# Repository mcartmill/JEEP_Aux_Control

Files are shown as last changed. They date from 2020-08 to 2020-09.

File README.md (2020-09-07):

# JEEP_Aux_Control
Control for aux accessories like additional lighting using a touchscreen control.

Goal

I am creating an open source solution to controlling additional electronic components such as lights.  

Conditions:
1.    Must be stand alone, not connecting to existing systems of the Jeep.
2.    Easy to customize
3.    Low Cost
4.    All documents available for anyone to use (code, PCB files, GRB files)
5.    Allow others to add to the documentation for functionality and defects

____________________________________________________________________________________
MCU Code

Code uses Ardiuno code for ease of use.
Jeep_AUX_Control.ino.ino

____________________________________________________________________________________
Touchscreen Code

Since using Nextion screen, UI code uses Nextion Editor Software - Free and easy to use.

____________________________________________________________________________________

Power Circuit code

Code for power circuit using ATTiny85 - attiny85powerlogicv0.1.ino

Power Circuit Theory of Operations

12V constant and 12V switched (identified as ignition in this document) comes into the circuit.  These are regulated down to 5V constant, 5V ignition, and 5V Ignition w/Delay off.

ATTiny85 is used to control 5V Ignition w/Delay by monitoring 5V Ignition into digital pin 0.  When digital pin 0 goes low, the chip sees this as ignition is off and then runs a delay and then sets digital pin 1 to low, which is the output that controls a transistor as a switch for the 5V Ignition w/Delay.

ATTiny85 Pinout
Pin4 = GND
Pin5= Digital Pin 0 = Input from 5V ignition
Pin6= Digital Pin 1 = Output to control transistor for delayed 5V ignition
Pin8= VCC (5V Constant)

Theory of Operations for ATTiny85 Code

Digital Pin0 = input
Digital Pin1 = output = init high

While pin0 is low then pin1==LOW

____________________________________________________________________________________
PCB

PCB files made in Eagle CAD.  Include ready to print files for https://jlcpcb.com/

Power Circuit PCB - power reg 5v_2019-04-10.zip

Control PCB JEEP_Aux_Control_PCB.brd and JEEP_Aux_Control_PCB.sch
JEEP_Aux_Control_PCB_2020-09-06.zip is the complete cam output to send to PCB house for production

____________________________________________________________________________________
BOM

BOM along with sources for parts
 
Control Board BOM
https://www.mouser.com/ProjectManager/ProjectDetail.aspx?AccessID=32fda13301

Power Board BOM
https://www.mouser.com/ProjectManager/ProjectDetail.aspx?AccessID=7aa37e28ff
 
Touchscreen
https://www.amazon.com/Nextion-NX4024T032-Display-Arduino-Raspberry/dp/B07QYRB38T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
 
Relays
https://www.amazon.com/ONLINE-LED-STORE-Pack-Interlocking/dp/B01KVZ2MU4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

____________________________________________________________________________________
3D models

____________________________________________________________________________________
Github file location:

https://github.com/mcartmill/JEEP_Aux_Control

____________________________________________________________________________________
Youtube videos

https://youtu.be/mUTJI6I0mCo

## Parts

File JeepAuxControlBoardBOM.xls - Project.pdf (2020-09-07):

JEEP AUX CONTROL
Mouser # | Mfr. # | Manufacturer | Customer # Description | RoHS | Lifecycle Order Qty. Price (USD) Ext.: (USD)
512-SB1100 | SB1100 | ON Semiconductor | Schottky Diodes & Rectifiers Schottky Diode | RoHS Compliant | 6 $0.36 | $2.16
559-FOXSD160-20-LF | FOXSDLF/160-20 | Fox | Crystals 16MHz 20pF | RoHS Compliant | 1 $0.27 | $0.27
581-06035A220J | 06035A220JAT2A | AVX | Multilayer Ceramic Capacitors MLCC - SMD/SMT 50V 22pF C0G 0603 5%RoHS Compliant | 2 $0.10 | $0.20
556-ATMEGA328P-PU | ATMEGA328P-PU | Microchip | 8-bit Microcontrollers - MCU 32KB In-system Flash 20MHz 1.8V-5.5V RoHS Compliant | 1 $2.08 | $2.08
571-1-2199298-9 | 1-2199298-9 | TE Connectivity | IC & Component Sockets 28P DIP SKT 300 CL LADDER | RoHS Compliant | 1 $0.46 | $0.46
594-MCT0603PD1001DP5 | MCT0603PD1001DP500 Vishay | Thin Film Resistors - SMD .250W 1Kohms .5% 0603 25ppm Hi Power | RoHS Compliant By Exemption | 6 $0.57 | $3.42
78-4N32 | 4N32 | Vishay | Transistor Output Optocouplers Photodarlington Out | RoHS Compliant | 6 $0.65 | $3.90

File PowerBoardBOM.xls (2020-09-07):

POWERBOARD
Mouser # | Mfr. # | Manufacturer | Customer # | Description | RoHS | Lifecycle | Order Qty. | Price (USD) | Ext.: (USD)
926-LM7805CT/NOPB | LM7805CT/NOPB | Texas Instruments |  | Linear Voltage Regulators 5 Volt Reg | RoHS Compliant |  | 2 | $1.54 | $3.08
81-GRM188R6YA106MA3D | GRM188R6YA106MA73D | Murata |  | Multilayer Ceramic Capacitors MLCC - SMD/SMT 0603 10uF 35volts *Derate Voltage/Temp | RoHS Compliant |  | 4 | $0.50 | $2.00
653-G5LE-1-ASIDC5 | G5LE-1-ASI DC5 | Omron |  | General Purpose Relays Power PCB Relay | RoHS Compliant |  | 1 | $1.45 | $1.45
594-MFU0805-FF-1.0 | MFU0805FF01000P500 | Vishay |  | Surface Mount Fuses 50V 1.0A Fast Act | RoHS Compliant |  | 2 | $0.41 | $0.82
556-ATTINY85-20SU | ATTINY85-20SU | Microchip |  | 8-bit Microcontrollers - MCU AVR 8K FLSH 512B EE 512B SRAM ADC 5V | RoHS Compliant |  | 1 | $1.13 | $1.13
512-2N3904BU | 2N3904BU | ON Semiconductor |  | Bipolar Transistors - BJT NPN Transistor General Purpose | RoHS Compliant |  | 2 | $0.20 | $0.40
621-1N4004 | 1N4004-T | Diodes Incorporated |  | Rectifiers Vr/400V Io/1A T/R | RoHS Compliant By Exemption |  | 1 | $0.19 | $0.19
575-1104730841001000 | 110-47-308-41-001000 | Mill-Max |  | IC & Component Sockets STANDRD SOLDER TAIL DIP SOCKET | RoHS Compliant |  | 1 | $0.51 | $0.51

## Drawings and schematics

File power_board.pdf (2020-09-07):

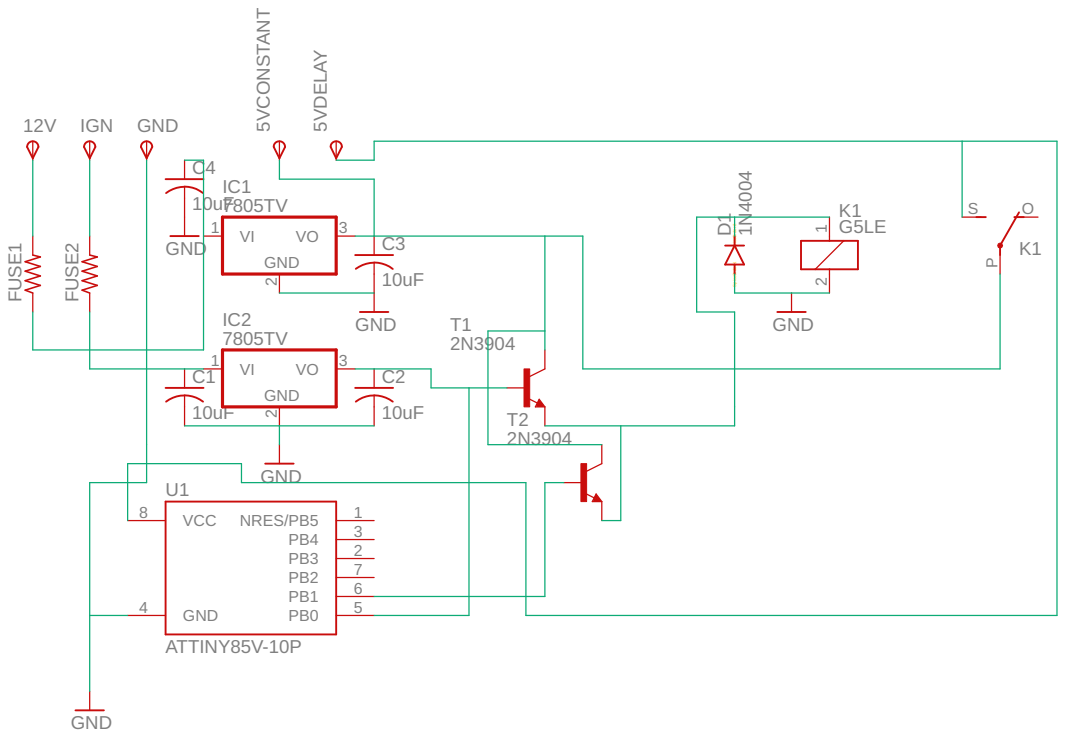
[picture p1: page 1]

SpiceOrder 1 SpiceOrder 2 ATTINY85V-10P GND 7805TV 7805TV 10uF 10uF 10uF 10uF GND GND GND 2N39042N3904 1G5LE N4004 GND PB0 5 PB1 6 PB2 7 PB3 2 PB4 3 NRES/PB5 1 VCC 8 GND 4 U1 12V IGN GND 5VCONSTANT 5VDELAY GND VI 1 2 VO 3 IC1 GND VI 1 2 VO 3 IC2 FUSE1 FUSE2 C1 C2 C3 C4 T1 T2 2 1 K1 S O P K1 D1

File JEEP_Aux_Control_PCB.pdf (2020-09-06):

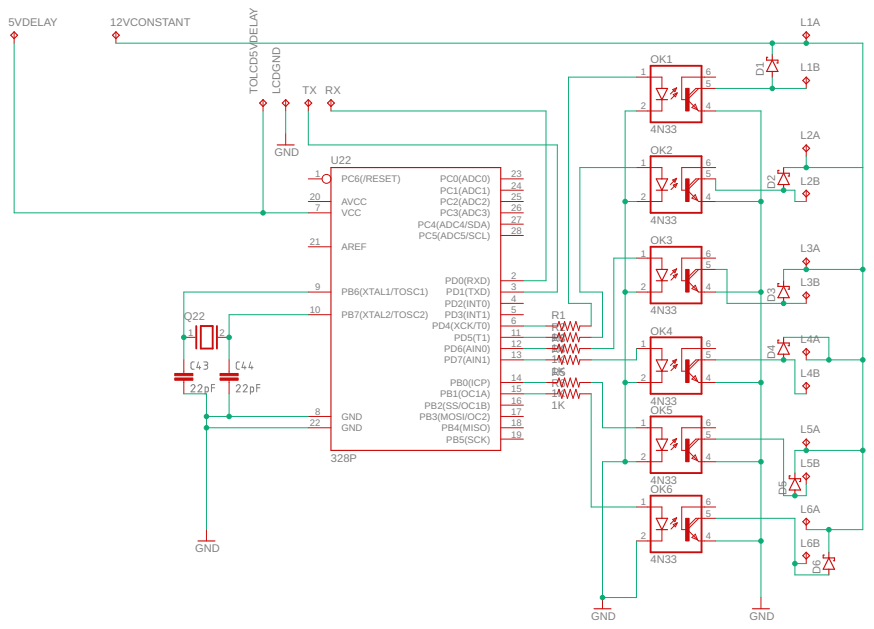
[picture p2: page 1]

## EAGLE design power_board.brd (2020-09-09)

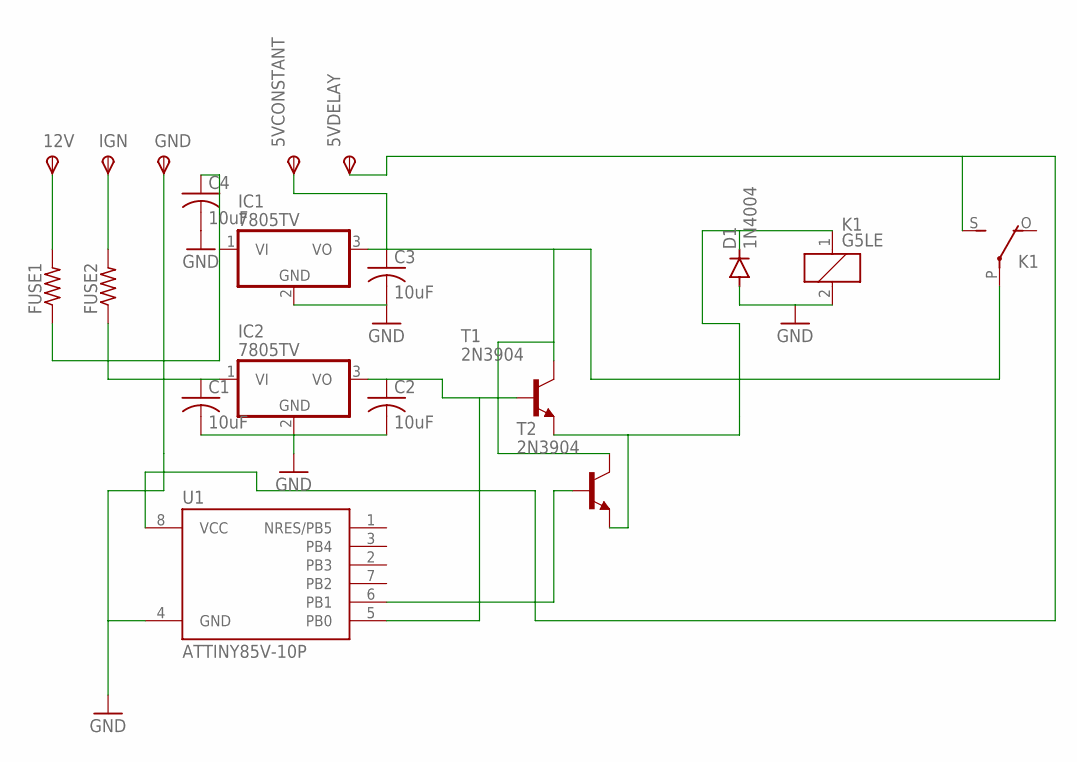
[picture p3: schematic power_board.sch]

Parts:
5VCONSTANT, 5VDELAY, 12V: TPSPAD1-13Y; P1-13Y
C1, C2, C3, C4: 10uF; C0603
D1: 1N4004; DO41-10
FUSE1, FUSE2: R-US_R0805; R0805
GND: TPSPAD1-13Y; P1-13Y
IC1, IC2: 7805TV; TO220V
IGN: TPSPAD1-13Y; P1-13Y
K1: G5LE
T1, T2: 2N3904; TO92
U1: ATTINY85V-10P; PDIP08_300MIL

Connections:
GND: C1.2, C2.2, C3.2, C4.2, D1.A, GND.TP, IC1.2 (GND), IC2.2 (GND), K1.2, U1.4 (GND)
unnamed: 12V.TP, FUSE1.2
unnamed: FUSE2.2, IGN.TP
unnamed: C1.1, FUSE2.1, IC2.1 (VI)
unnamed: C4.1, FUSE1.1, IC1.1 (VI)
unnamed: C2.1, IC2.3 (VO), T1.2 (B), U1.5 (PB0)
unnamed: 5VCONSTANT.TP, C3.1, IC1.3 (VO), K1.P, T1.1 (C), T2.1 (C)
unnamed: D1.C, K1.1, T1.3 (E), T2.3 (E)
unnamed: 5VDELAY.TP, K1.S, U1.8 (VCC)
unnamed: T2.2 (B), U1.6 (PB1)

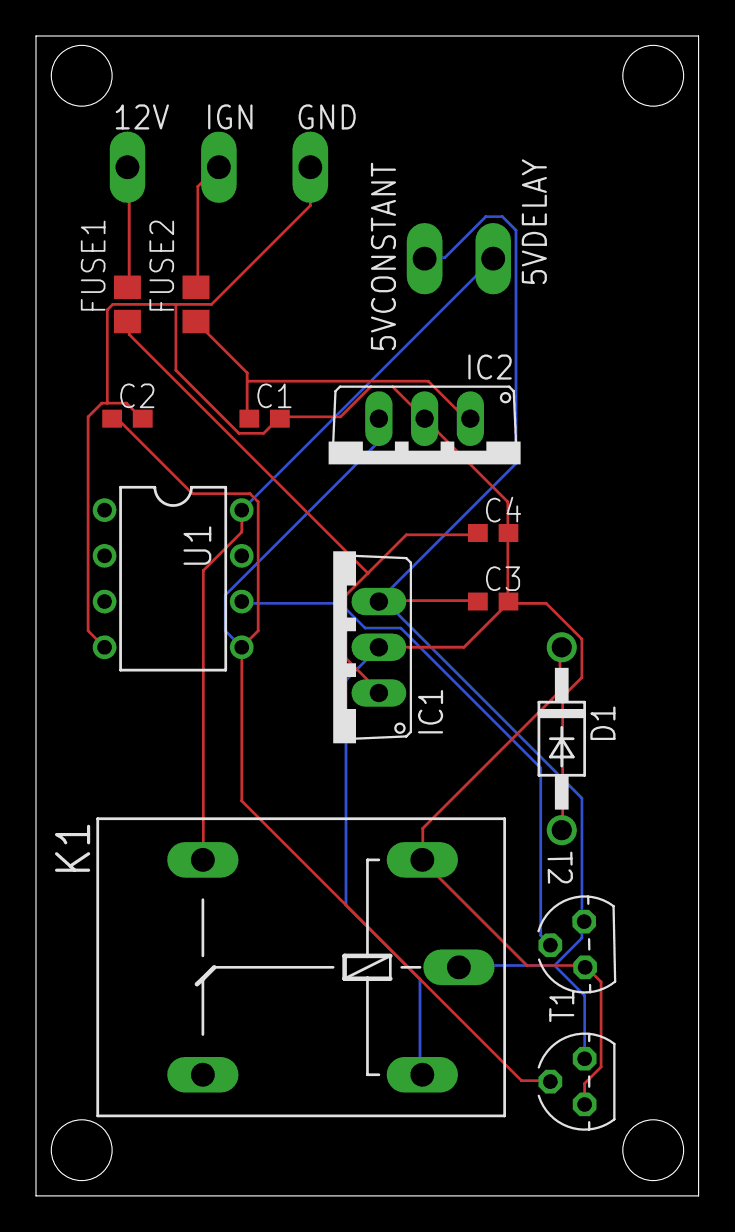
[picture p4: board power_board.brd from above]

Board: 2 copper layers, 36.8 x 64.4 mm, 18 parts (0 on the bottom side), 10 nets.

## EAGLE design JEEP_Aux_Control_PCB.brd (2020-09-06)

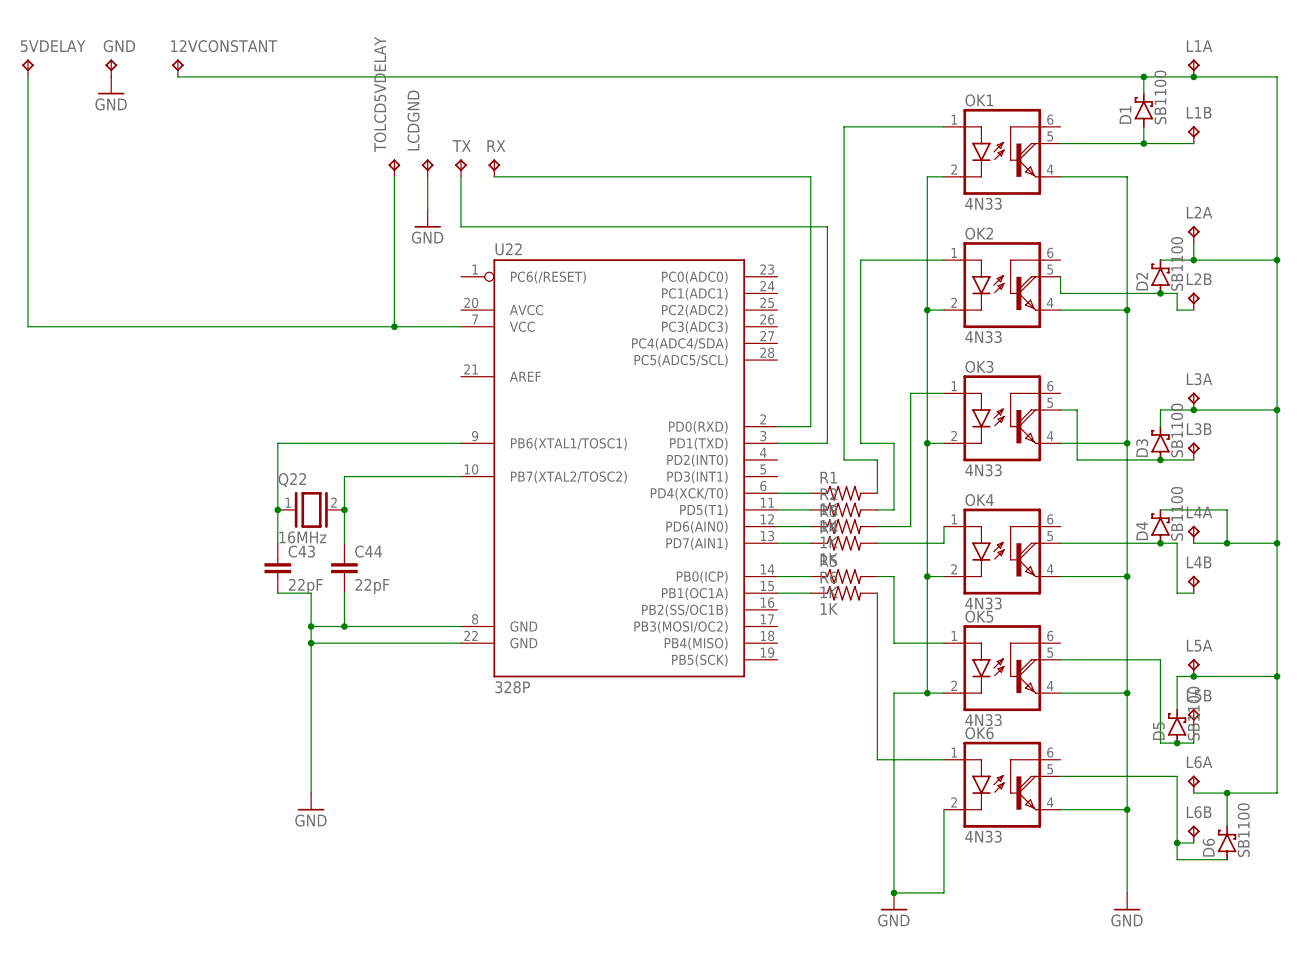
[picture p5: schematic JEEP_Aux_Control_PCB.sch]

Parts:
5VDELAY, 12VCONSTANT: TPPAD1-13Y; P1-13Y
C43, C44: 22pF; CAP-PTH-2.54
D1, D2, D3, D4, D5, D6: SB1100; CB417-15
GND: TPPAD1-13Y; P1-13Y
L1A, L1B, L2A, L2B, L3A, L3B, L4A, L4B, L5A, L5B, L6A, L6B: TPPAD1-13Y; P1-13Y
LCDGND: TPPAD1-13Y; P1-13Y
OK1, OK2, OK3, OK4, OK5, OK6: 4N33; DIL06
Q22: 16MHz; Q
R1, R2, R3, R4, R5, R6: 1K; R0603
RX: TPPAD1-13Y; P1-13Y
TOLCD5VDELAY: TPPAD1-13Y; P1-13Y
TX: TPPAD1-13Y; P1-13Y
U22: 328P; DIP28

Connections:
GND: C43.2, C44.2, GND.TP, LCDGND.TP, OK1.2 (C), OK1.4 (E), OK2.2 (C), OK2.4 (E), OK3.2 (C), OK3.4 (E), OK4.2 (C), OK4.4 (E), OK5.2 (C), OK5.4 (E), OK6.2 (C), OK6.4 (E), U22.8 (GND), U22.22 (GND)
unnamed: R1.1, U22.6 (PD4(XCK/T0))
unnamed: R2.1, U22.11 (PD5(T1))
unnamed: R3.1, U22.12 (PD6(AIN0))
unnamed: R4.1, U22.13 (PD7(AIN1))
unnamed: R5.1, U22.14 (PB0(ICP))
unnamed: R6.1, U22.15 (PB1(OC1A))
unnamed: OK1.1 (A), R1.2
unnamed: OK2.1 (A), R2.2
unnamed: OK3.1 (A), R3.2
unnamed: OK4.1 (A), R4.2
unnamed: OK5.1 (A), R5.2
unnamed: OK6.1 (A), R6.2
unnamed: D1.A, L1B.TP, OK1.5 (COL)
unnamed: D2.A, L2B.TP, OK2.5 (COL)
unnamed: D3.A, L3B.TP, OK3.5 (COL)
unnamed: D4.A, L4B.TP, OK4.5 (COL)
unnamed: D5.A, L5B.TP, OK5.5 (COL)
unnamed: D6.A, L6B.TP, OK6.5 (COL)
unnamed: TX.TP, U22.3 (PD1(TXD))
unnamed: 5VDELAY.TP, TOLCD5VDELAY.TP, U22.7 (VCC)
unnamed: RX.TP, U22.2 (PD0(RXD))
unnamed: 12VCONSTANT.TP, D1.C, D2.C, D3.C, D4.C, D5.C, D6.C, L1A.TP, L2A.TP, L3A.TP, L4A.TP, L5A.TP, L6A.TP
unnamed: C43.1, Q22.1, U22.9 (PB6(XTAL1/TOSC1))
unnamed: C44.1, Q22.2, U22.10 (PB7(XTAL2/TOSC2))

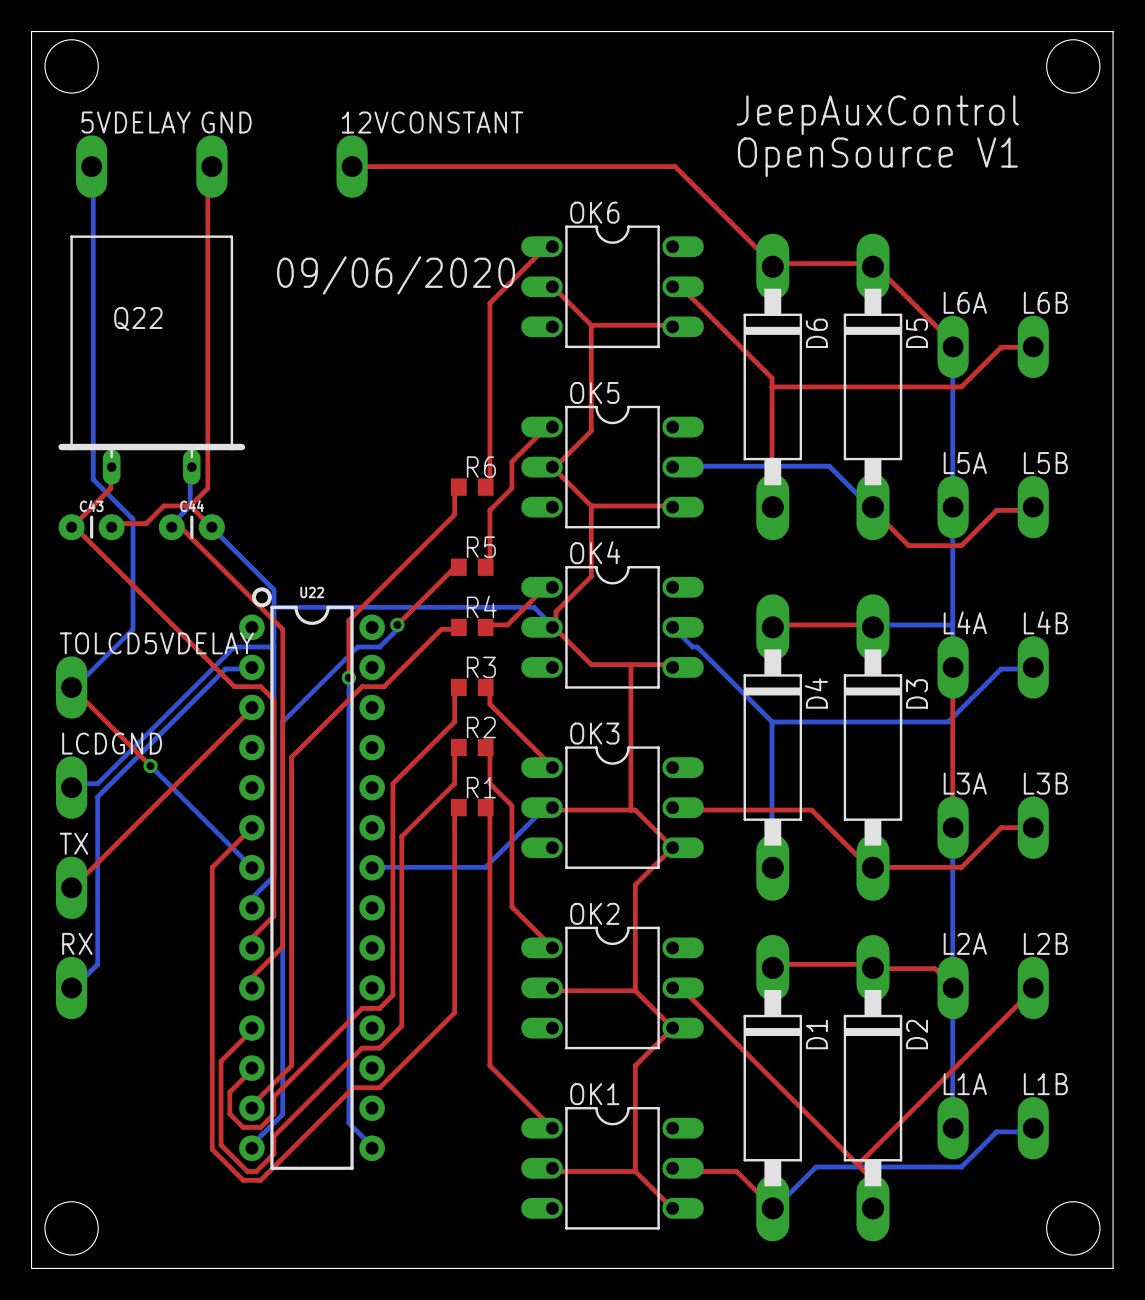
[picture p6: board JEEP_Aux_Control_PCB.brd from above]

Board: 2 copper layers, 68.6 x 78.4 mm, 41 parts (0 on the bottom side), 25 nets.

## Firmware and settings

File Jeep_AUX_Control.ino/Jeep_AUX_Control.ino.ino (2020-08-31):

/*
 * 08/30/2020  date created
 * Version 0.1
 * 
 * 
 * 
 * Proof of concept code
 * 
 *
 * 
 * ATMega328P-PU chipset
 * Using Arduino Uno 
 * 
 * 
 * 
 * Using just chip and 16.00 MHZ crystal with 22pF caps to ground
*/



#include <Nextion.h>  //  https://github.com/itead/ITEADLIB_Arduino_Nextion





// Declare buttons

NexDSButton bt0 = NexDSButton(0, 1, "bt0");   // Dual state button added
NexDSButton bt1 = NexDSButton(0, 2, "bt1");
NexDSButton bt2 = NexDSButton(0, 3, "bt2");  
NexDSButton bt3 = NexDSButton(0, 4, "bt3");
NexDSButton bt4 = NexDSButton(0, 5, "bt4");
NexDSButton bt5 = NexDSButton(0, 6, "bt5");




// Declare touch event objects: 

NexTouch *nex_listen_list[] = 
{
  &bt0,  // dual utton added
  &bt1,
  &bt2,
  &bt3,
  &bt4,
  &bt5,
  //&b0 = button, &bt0 = Dual state button


  NULL  // String terminated
}; 




// Touch event actions:

void bt0PushCallback(void *ptr)  // Press event for dual state button bt0
{
  uint32_t light0 = 0;  // Create variable for button
  bt0.getValue(&light0);  // Read value of button

  if(light0 == 1){
    digitalWrite(4, HIGH);  
  }else{  // 
    digitalWrite(4, LOW); 
  }
}

void bt1PushCallback(void *ptr)  // Press event for dual state button bt0
{
  uint32_t light1 = 0;  // Create variable for button
  bt1.getValue(&light1);  // Read value of button

  if(light1 == 1){
    digitalWrite(5, HIGH);  
  }else{  // 
    digitalWrite(5, LOW); 
  }
}

void bt2PushCallback(void *ptr)  // Press event for dual state button bt0
{
  uint32_t light2 = 0;  // Create variable for button
  bt2.getValue(&light2);  // Read value of button

  if(light2 == 1){
    digitalWrite(6, HIGH);  
  }else{  // 
    digitalWrite(6, LOW); 
  }
} 

void bt3PushCallback(void *ptr)  // Press event for dual state button bt0
{
  uint32_t light3 = 0;  // Create variable for button
  bt3.getValue(&light3);  // Read value of button

  if(light3 == 1){
    digitalWrite(7, HIGH);  
  }else{  // 
    digitalWrite(7, LOW); 
  }
}

void bt4PushCallback(void *ptr)  // Press event for dual state button bt0
{
  uint32_t light4 = 0;  // Create variable for button
  bt4.getValue(&light4);  // Read value of button

  if(light4 == 1){
    digitalWrite(8, HIGH);  
  }else{  // 
    digitalWrite(8, LOW); 
  }
}

void bt5PushCallback(void *ptr)  // Press event for dual state button bt0
{
  uint32_t light5 = 0;  // Create variable for button
  bt5.getValue(&light5);  // Read value of button

  if(light5 == 1){
    digitalWrite(9, HIGH);  
  }else{  // 
    digitalWrite(9, LOW); 
  }
} 



void setup()  // Start of setup
{

  Serial.begin(115200);  // Set baud rate and start serial comms
  


  // Register touch events:

 bt0.attachPush(bt0PushCallback);  // Dual state button press
 bt1.attachPush(bt1PushCallback);
 bt2.attachPush(bt2PushCallback);
 bt3.attachPush(bt3PushCallback);
 bt4.attachPush(bt4PushCallback);
 bt5.attachPush(bt5PushCallback);
 
  // End of registering the event callback functions

  pinMode(4, OUTPUT);
  pinMode(5, OUTPUT);
  pinMode(6, OUTPUT);
  pinMode(7, OUTPUT);
  pinMode(8, OUTPUT);
  pinMode(9, OUTPUT);
}  // End of setup


void loop()  // Start of loop
{
  nexLoop(nex_listen_list);  // Check for any touch event
}

  // End of loop

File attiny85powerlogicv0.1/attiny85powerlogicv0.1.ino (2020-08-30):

/*Power circuit logic code
 * 
 * Monitors switched iginiton power 
 * using ATTiny85 chip
 * 
 * when ignition gets turned off, output stays on for delay time
 * and then gets turned off after delay is over.
 * 
 * Mike Cartmill
 * 09/13/2019
 * V0.1
 */

void setup() {
  // put your setup code here, to run once:
digitalWrite(0,HIGH);  //sets pin0 output to High
pinMode(0, OUTPUT);  //output pin
pinMode(1,INPUT);  //input pin

}

void loop() {
  

  while (digitalRead(1) == LOW){ //when pin1 goes low
  delay(5000); //waits for time in ms  (n/1000=seconds)
  digitalWrite(0,LOW);  //turn off output pin0
  }
}

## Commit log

2020-08-30 Initial upload of grb files for Power PCB
2020-08-30 Power Cirucuit Code
    Code for ATTiny85 in power circuit
2020-08-30 Update README.md
    Added Power circuit PCB files and Power Circuit ATTiny85 code
2020-08-30 Initial Control PCB Design
    [JEEP_Aux_Control_PCB.brd, JEEP_Aux_Control_PCB.sch]
2020-08-30 updated to distinguish control PCB files
2020-09-06 control schematic update
    [JEEP_Aux_Control_PCB.csv]
2020-09-06 Cleanup of schematic
    [JEEP_Aux_Control_PCB.csv]
2020-09-06 PCB update for v1
    v1 Control PCB - submitted to PCB house
    [JEEP_Aux_Control_PCB.brd, JEEP_Aux_Control_PCB.sch]
2020-09-07 update of BOM
    [JeepAuxControlBoardBOM.xlsx]
2020-09-07 Updated BOM info
2020-09-07 Updated JeepControl PCB CAM info
2020-09-07 update of powerboard docs
    [PowerBoardBOM.xls, power_board.sch]
2020-09-07 PowerBoard PCB
    [power_board.brd]
2020-09-09 power board update
    [power_board.brd, power_board.sch]

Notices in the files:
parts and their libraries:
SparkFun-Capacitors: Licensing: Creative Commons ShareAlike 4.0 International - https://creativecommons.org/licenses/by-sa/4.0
